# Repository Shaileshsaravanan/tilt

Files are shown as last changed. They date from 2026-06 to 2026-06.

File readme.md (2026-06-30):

Galvanic Vestibular Stimulation (GVS)

custom galvanic vestibular stimulation device to control/hack your balance

## context

galvanic vestibular stimulation (gvs) delivers low-current dc signals (1-2 ma) across the mastoid processes to hack your balance. the cathode depolarizes the vestibular nerves to increase their firing rate, while the anode hyperpolarizes them to decrease it. your brain perceives this mismatch as physical tilt, forcing your body to instinctively lean toward the anode to compensate.

## schematic

1. control (esp-01)
   generates complementary pwm and direction signals. gpio0 and gpio2 need pull-up/pull-down resistors to force a known safe state during bootup so they don't float and trigger the stimulation rail on power-up

2. power boost (mt3608)
   steps up 3.7v input to a stable 12v-15v rail. this high headroom is required to break through skin-electrode impedance, which easily sits around 5k-10k ohms on dry skin

3. galvanic isolation
   optoisolators decouple the microcontroller's logic from the stimulation stage. this shields your head from any potential mains-side faults or grounding issues if you ever plug the esp-01 into a usb port to debug

4. active constant-current regulation
   the critical safety gate. uses an lm334 or a closed-loop feedback op-amp to clamp the current to a strict 1.5ma-2ma. this overrides the dynamic drop in skin resistance so you don't get a sudden, uncontrolled current spike

5. h-bridge polarity control
   uses a matched array of 2n3906 (pnp) and 2n3904 (npn) transistors. dynamically reverses the current path across the electrode array, swapping which mastoid acts as the cathode and which acts as the anode for left/right tilt

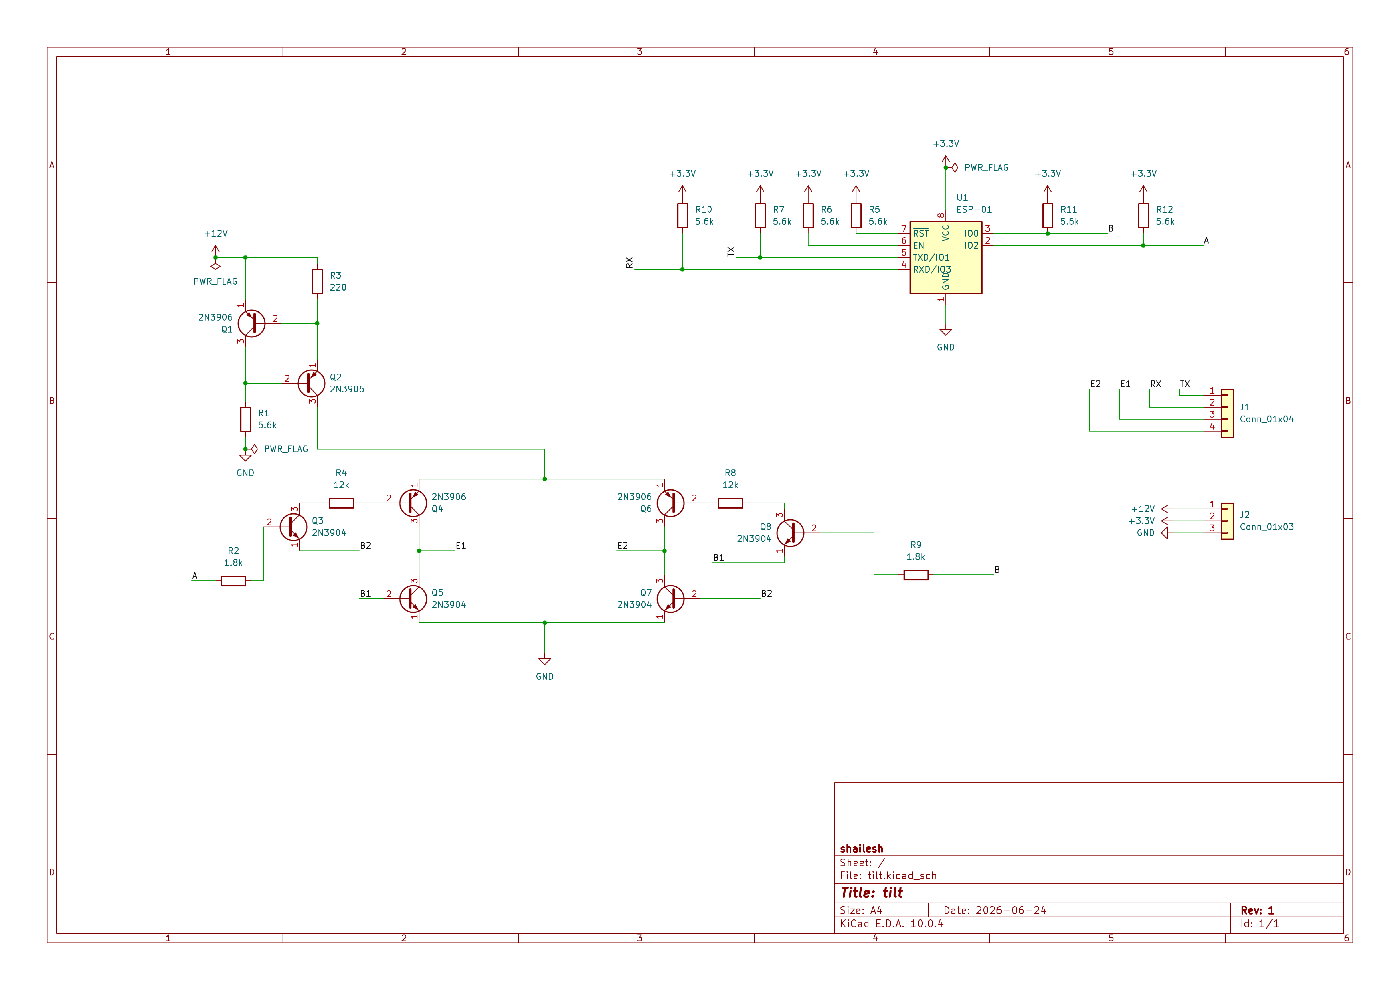
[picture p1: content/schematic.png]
schematic


## pcb

i just wanted a non rectangular shaped pcb so i just made it into a random polygon

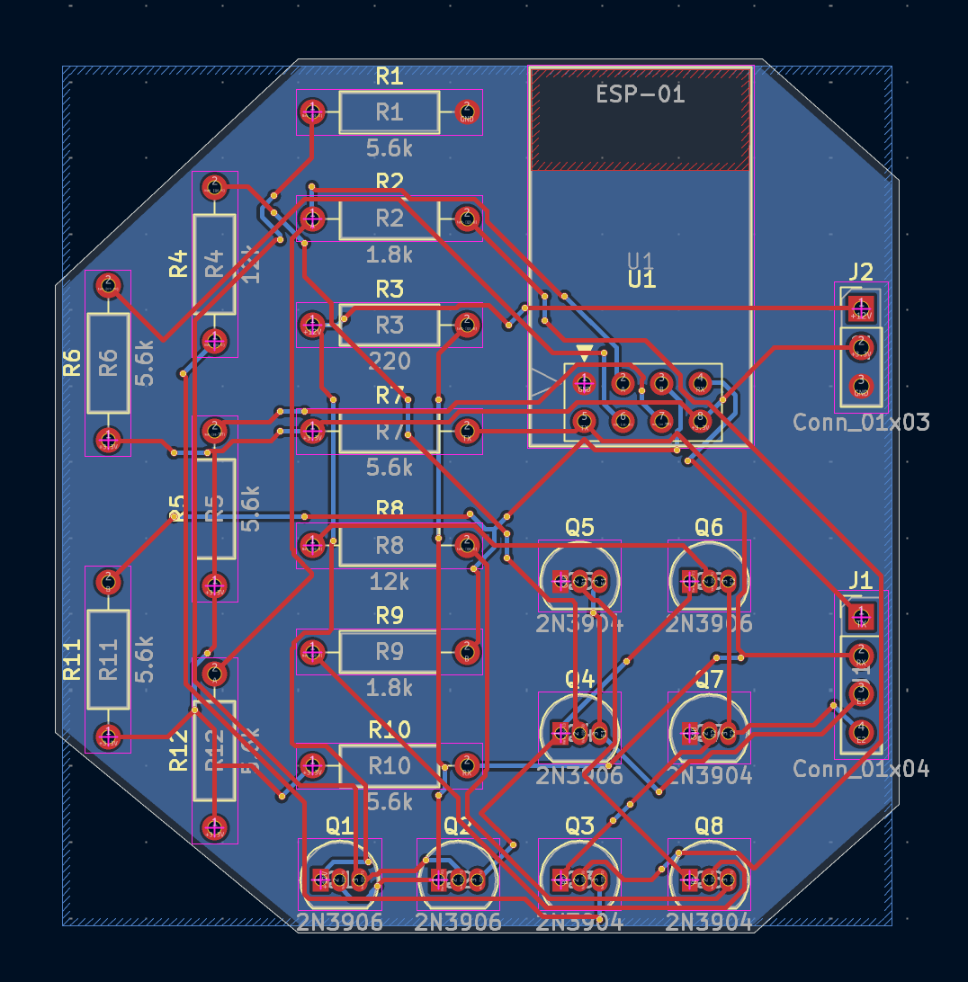
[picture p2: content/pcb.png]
pcb


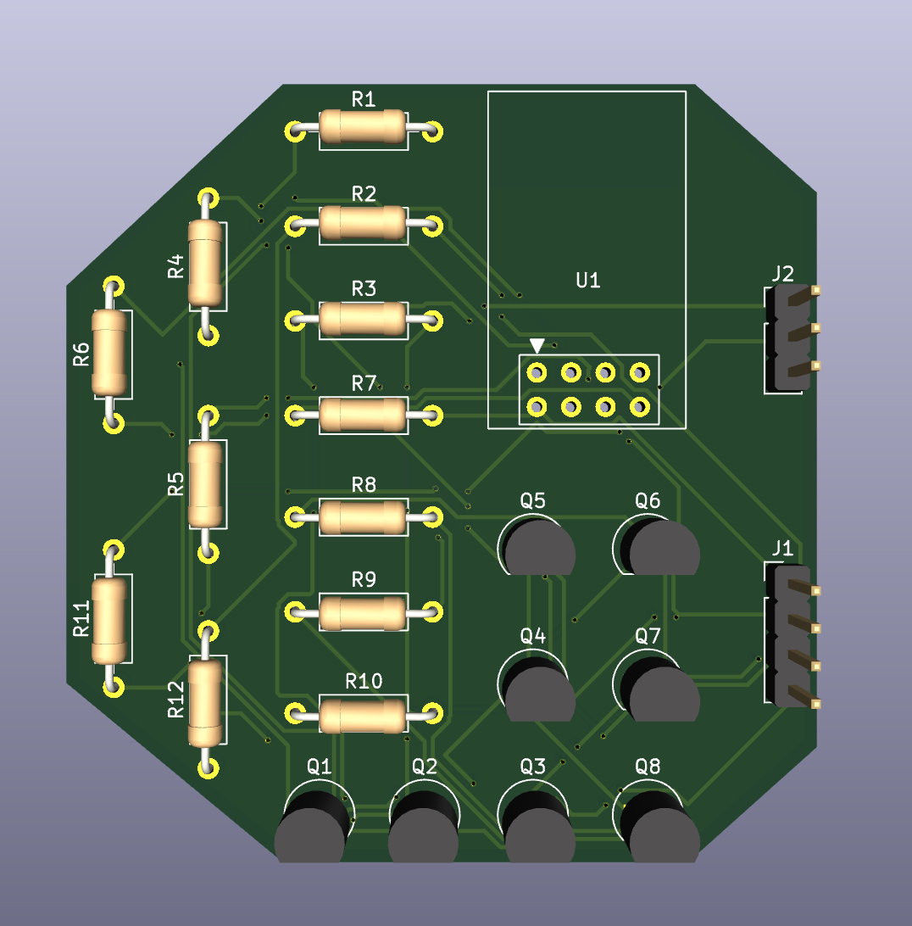
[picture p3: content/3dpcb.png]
3d pcb


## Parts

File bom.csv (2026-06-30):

Item | Quantity Needed | Cost of product | Source Link
JST-XH Connector Kit | 1 | $6.5 | https://www.amazon.in/MTRoyaldia-560PCS-Connector-Housing-Adapter/dp/B0GTPGBC7S
Female Berg Strip Connector | 10 | $2 | https://www.amazon.in/Electronic-Spices-Female-Connector-Projects/dp/B0BG7K3NGV
Male Berg Strip Connector | 10 | $2 | https://www.amazon.in/Electronic-Spices-Strip-Headers-Sticks/dp/B0BG7K3CGM
2N3906 PNP Transistor | 4 | $2 | https://www.amazon.in/2N3906-General-Purpose-Transistor-Package/dp/B09Z8HLFBJ?s=industrial
2N3904 NPN Transistor | 4 | $2 | https://www.amazon.in/2N3904-Transistor-Pack-of-2/dp/B08NV8DRKD?s=industrial
5.6k resistors | 7 | $2 | https://www.amazon.in/5-6k-Ohm-Resistor-Tolerance-Pack/dp/B0DQFHWP9K?s=industrial
220 resistors | 1 | $2 | https://www.amazon.in/Electronic-Spices-Tolerance-Through-Resistors/dp/B0BDG2F7FL?s=industrial
12k resistors | 2 | $2 | https://www.amazon.in/12k-Ohm-Resistor-Tolerance-Pack/dp/B0DQFLY6Z2?s=industrial
1.8k resistors | 2 | $2 | https://www.amazon.in/1-8k-Ohm-Resistor-Tolerance-Pack/dp/B0DQFFJXKB?s=industrial
MT3608 Module | 1 | $3 | https://www.amazon.in/Voltage-Booster-Adjustable-converter-Regulator/dp/B0C39FRFM8?rnid=10440598031&rps=1
ESP-8266 01 | 2 (they tend to be faulty) | $3 | https://www.amazon.in/Robodo-MO16-Esp8266-Wireless-Transceiver/dp/B073Q2X8G7
AA Batteries | 12 | $6 | https://www.amazon.in/Duracell-AA-High-Drain-Electric-Toothbrush/dp/B01DJJVF1Q
Battery Enclosure + Wires | 1 | $2 | https://www.amazon.in/Electronic-Spices-Battery-Plastic-7-4volt/dp/B0BFWFKGHW
3.5 mm mono (TS) jack | 1 | $5 | https://www.amazon.in/ECOMISTIQ%C2%AE-Connector-Interconnects-Accessories-Electronics/dp/B0GZ483Y6D
Switch | 1 | $3 | https://www.amazon.in/Electronic-Spices-Toggle-Position-Miniature/dp/B09WDKT8DK
Soldering Iron kit | 1 | $15 | https://www.amazon.in/ElectroSea-Soldering-80W-Adjustable-Desoldering/dp/B0GWFR2LL5?s=industrial
Soldering Paste (Flux) | 1 | $5 | https://www.amazon.in/TOWOT-Solder-Soldering-Paste-Electronics/dp/B0CNVM1KRT?s=industrial
Soldering wire | 1 | $5 | https://www.amazon.in/GREENARTZ-Soldering-core-Aluminium-Copper/dp/B0BNLQX91R?s=industrial
Soldering Helping hands | 1 | $5 | https://www.amazon.in/Robocraze-Magnifier-Soldering-Adjustable-Electronics/dp/B0GQ46HFNJ
Wires | 1 | $4 | https://www.amazon.in/ElectronicSpices-Electric-Science-Projects-Building/dp/B081Z8CY53
Electrode Pads (Similar to TENS pads) | Pack of 2 | $12 | https://www.amazon.in/NEYMA-Adhesive-Electrode-Electronic-Stimulator/dp/B08XYXS3MN
Electrode Wires | 1 | $13 | https://www.amazon.in/KONMED-Electrode-Standard-Connection-Long-life/dp/B00P67NIQ0
Jumper Wires | 1 | $2.5 | https://www.amazon.in/Aptechdeals-Jumper-Wires-Female-Breadboard/dp/B074JB6SX8
Expedited Shipping for PCB | - | $26 | -
Total |  | ~$146 | -

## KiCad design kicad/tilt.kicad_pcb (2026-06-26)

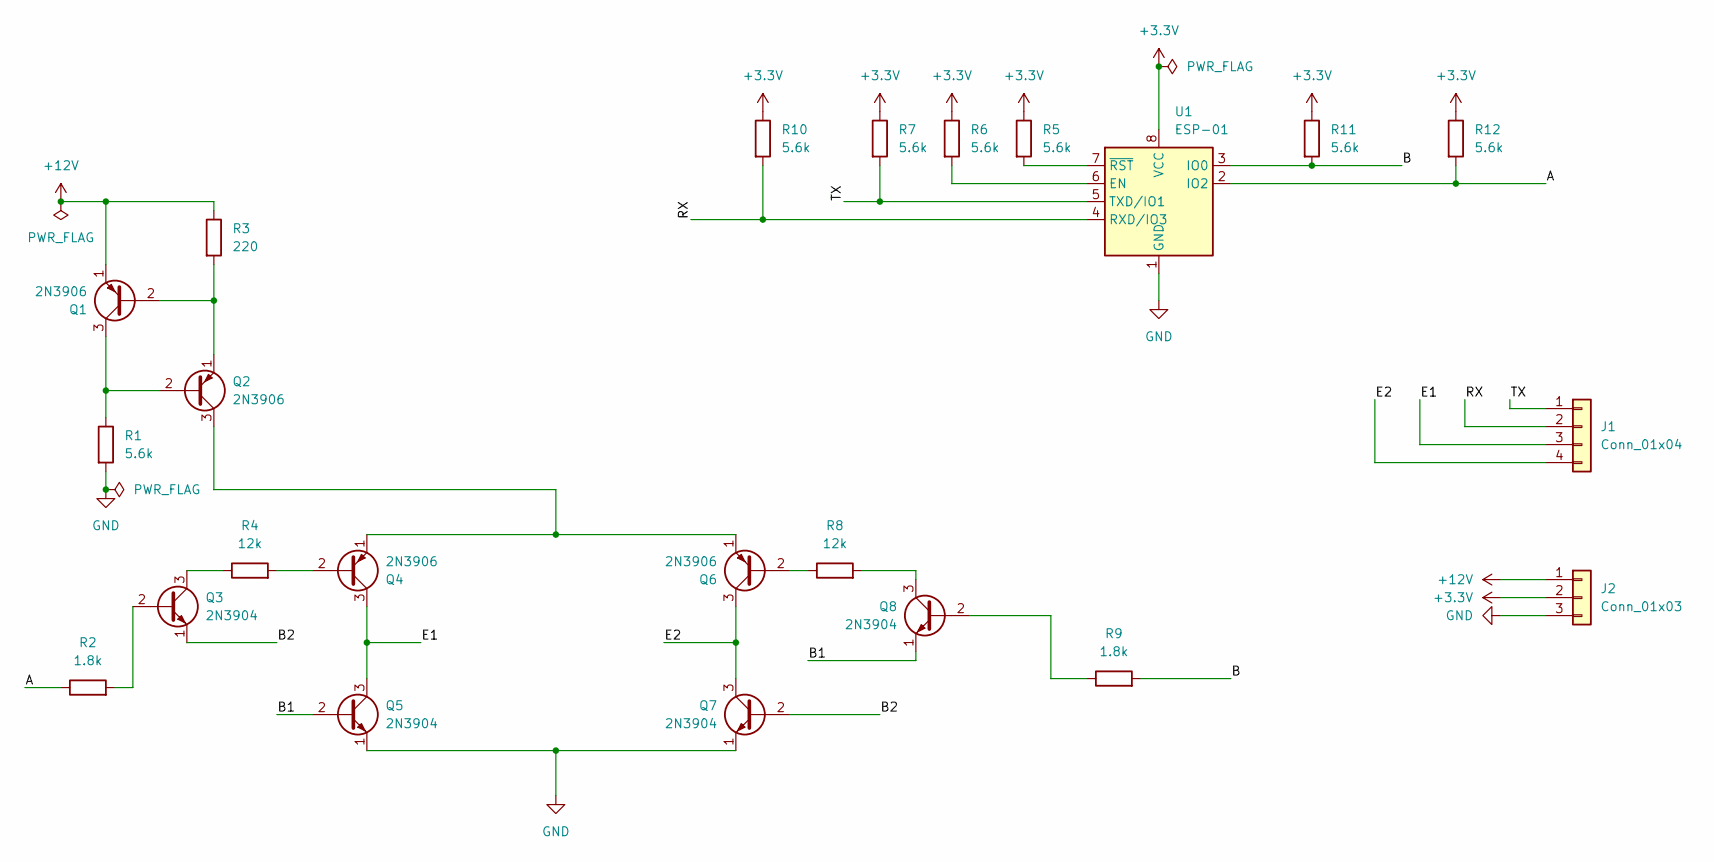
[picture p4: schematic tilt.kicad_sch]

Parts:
J1: Conn_01x04; PinHeader_1x04_P2.54mm_Vertical
J2: Conn_01x03; PinHeader_1x03_P2.54mm_Vertical
Q1, Q2, Q4, Q6: 2N3906; TO-92_Inline
Q3, Q5, Q7, Q8: 2N3904; TO-92_Inline
R1, R5, R6, R7, R10, R11, R12: 5.6k; R_Axial_DIN0207_L6.3mm_D2.5mm_P10.16mm_Horizontal
R2, R9: 1.8k; R_Axial_DIN0207_L6.3mm_D2.5mm_P10.16mm_Horizontal
R3: 220; R_Axial_DIN0207_L6.3mm_D2.5mm_P10.16mm_Horizontal
R4, R8: 12k; R_Axial_DIN0207_L6.3mm_D2.5mm_P10.16mm_Horizontal
U1: ESP-01

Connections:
+3.3V: J2.2, R5.1, R6.1, R7.1, R10.1, R11.1, R12.1, U1.8 (VCC)
+12V: J2.1, Q1.1 (E), R3.1
/A: R2.1, R12.2, U1.2 (IO2)
/B: R9.2, R11.2, U1.3 (IO0)
/B1: Q5.2 (B), Q8.1 (E)
/B2: Q3.1 (E), Q7.2 (B)
/E1: J1.3, Q4.3 (C), Q5.3 (C)
/E2: J1.4, Q6.3 (C), Q7.3 (C)
/RX: J1.2, R10.2, U1.4 (RXD/IO3)
/TX: J1.1, R7.2, U1.5 (TXD/IO1)
GND: J2.3, Q5.1 (E), Q7.1 (E), R1.2, U1.1 (GND)
unnamed: Q1.2 (B), Q2.1 (E), R3.2
unnamed: Q1.3 (C), Q2.2 (B), R1.1
unnamed: Q2.3 (C), Q4.1 (E), Q6.1 (E)
unnamed: Q3.2 (B), R2.2
unnamed: Q3.3 (C), R4.1
unnamed: Q4.2 (B), R4.2
unnamed: Q6.2 (B), R8.1
unnamed: Q8.2 (B), R9.1
unnamed: Q8.3 (C), R8.2
unnamed: R6.2, U1.6 (EN)
unnamed: R5.2, U1.7 (~RST)

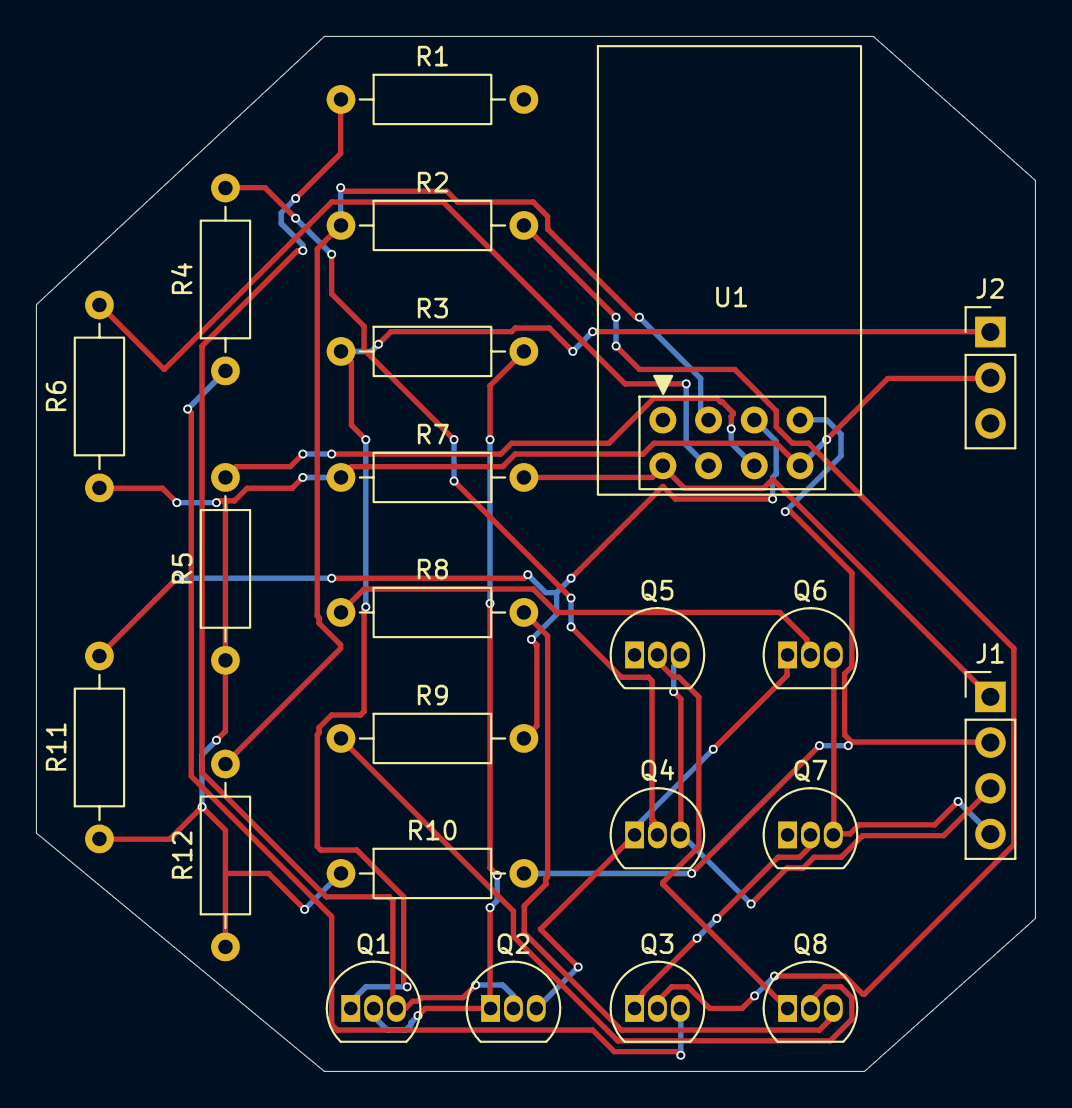
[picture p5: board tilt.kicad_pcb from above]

Board: 2 copper layers, 55.5 x 57.5 mm, 23 parts (0 on the bottom side), 22 nets.

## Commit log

2026-06-26 updated readme + kicad folder
    [tilt-B_Cu.gbr, tilt-B_Mask.gbr, tilt-B_Paste.gbr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]
2026-06-30 added bom.csv
    [bom.csv]
